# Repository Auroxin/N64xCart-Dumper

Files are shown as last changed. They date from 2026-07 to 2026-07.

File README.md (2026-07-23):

# N64xCart Dumper

N64xCart Dumper is an open hardware / firmware project for dumping Nintendo 64 cartridges as a USB mass storage device. It is based on the excellent DreamDumper64 project and the `DrmDmp64_mass` firmware, with changes for the N64xCart Dumper hardware.

## Project Status

This repository contains:

- `firmware/N64xCartDumper/` - RP2040 firmware adapted for the N64xCart Dumper board.
- `hardware/PCB/` - KiCad schematic and PCB layout.
- `hardware/production/` - production files for PCB manufacturing.
- `extras/` - extra project files, if any.

The device appears to the computer as a USB mass storage device. The virtual FAT16 disk exposes N64 cartridge data and save data files such as ROM, EEPROM, SRAM and FlashRAM where supported by the firmware.

### Known Issues – CIC Detection

The current hardware revision (v1.x) does not provide a clock signal to the CIC (Copy Integrity Check) chip inside the cartridge. Under normal operation, this clock signal is supplied by the N64 console itself. Since the clock is not connected in this hardware version, the CIC chip on the cartridge cannot function properly during operation.
Impact
Save backup functionality: ✅ NOT affected. The CIC error does not interfere with the ability to read or back up save data from the cartridge. You can safely use the backup feature.
A future hardware revision is planned to address this issue. The updated design will include the necessary clock routing to the CIC chip, allowing proper CIC detection and verification.

## Origin and Credits

This project exists because of prior open source work. Please visit and support the original authors:

- DreamDumper64 hardware project by khill25: https://github.com/khill25/Dreamdumper
- `DrmDmp64_mass` firmware by nopjne: https://github.com/nopjne/drmdmp64_mass
- TinyUSB USB stack: https://github.com/hathach/tinyusb
- Raspberry Pi Pico / RP2040 SDK ecosystem: https://github.com/raspberrypi/pico-sdk

My changes are focused on adapting the firmware and hardware layout for the N64xCart Dumper board, including the PCB layout, production files, and acrylic enclosure design.

## Hardware

The hardware in this repository was redrawn and laid out for the N64xCart Dumper form factor while following the DreamDumper64 hardware principles.

Current hardware files:

- KiCad project: `hardware/PCB/N64xCartDumper-v1.1.kicad_pro`
- Schematic: `hardware/PCB/N64xCartDumper-v1.1.kicad_sch`
- PCB layout: `hardware/PCB/N64xCartDumper-v1.1.kicad_pcb`
- Production archive: `hardware/production/N64xCart-Dumper-v1.1-20260612.zip`

## Firmware

The firmware is based on `DrmDmp64_mass`, a mass storage device firmware for DreamDumper64. It has been modified for the N64xCart Dumper hardware.

Important local changes include:

- USB product strings changed to `N64xCart Dumper`.
- Hardware pin and LED configuration adapted for this board.
- Virtual disk label/product information updated for N64xCart Dumper.
- Project files arranged under `firmware/N64xCartDumper/`.

## Building Firmware

The active firmware build entry is the CMake project in `firmware/N64xCartDumper/`.

Typical build flow:

```sh
cd firmware/N64xCartDumper
mkdir build
cd build
cmake ..
cmake --build .
(optional) put pico in bootloader mode and copy the N64xCartDumper.uf2 to the attached drive.
```

You will need a working Raspberry Pi Pico / RP2040 build environment, including the Pico SDK, CMake, a supported ARM GCC toolchain, and the TinyUSB dependencies used by this project.

Note: the included `Makefile` appears to be inherited from an earlier TinyUSB example layout and may not match the current source file names. Prefer the CMake build unless you intentionally update the Makefile.

## Buying a Finished Unit

I also sell assembled N64xCart Dumper units on AliExpress. Buying one helps support the time spent on PCB layout, testing, assembly, enclosure design, and continued open source maintenance.

- Support Us: [Product Link](https://www.aliexpress.com/item/1005012654363194.html)

Thank you for supporting this project. If you build your own, improve the design, or find a bug, contributions and feedback are welcome.

## License Notes

This repository contains code and design work derived from other open source projects. Please check the original projects and bundled third-party files for their license terms:

- `DrmDmp64_mass`: https://github.com/nopjne/drmdmp64_mass
- DreamDumper64: https://github.com/khill25/Dreamdumper
- TinyUSB license file included at `firmware/N64xCartDumper/external/tinyusb/LICENSE`

Source files inherited from `DrmDmp64_mass` include their original copyright and license headers. New N64xCart Dumper hardware files and modifications should be used with respect for the upstream projects and their licenses.

## Disclaimer

This is an independent hobbyist/open hardware project. It is not affiliated with or endorsed by Nintendo. Use it only with cartridges and data you legally own and are allowed to back up under your local laws.

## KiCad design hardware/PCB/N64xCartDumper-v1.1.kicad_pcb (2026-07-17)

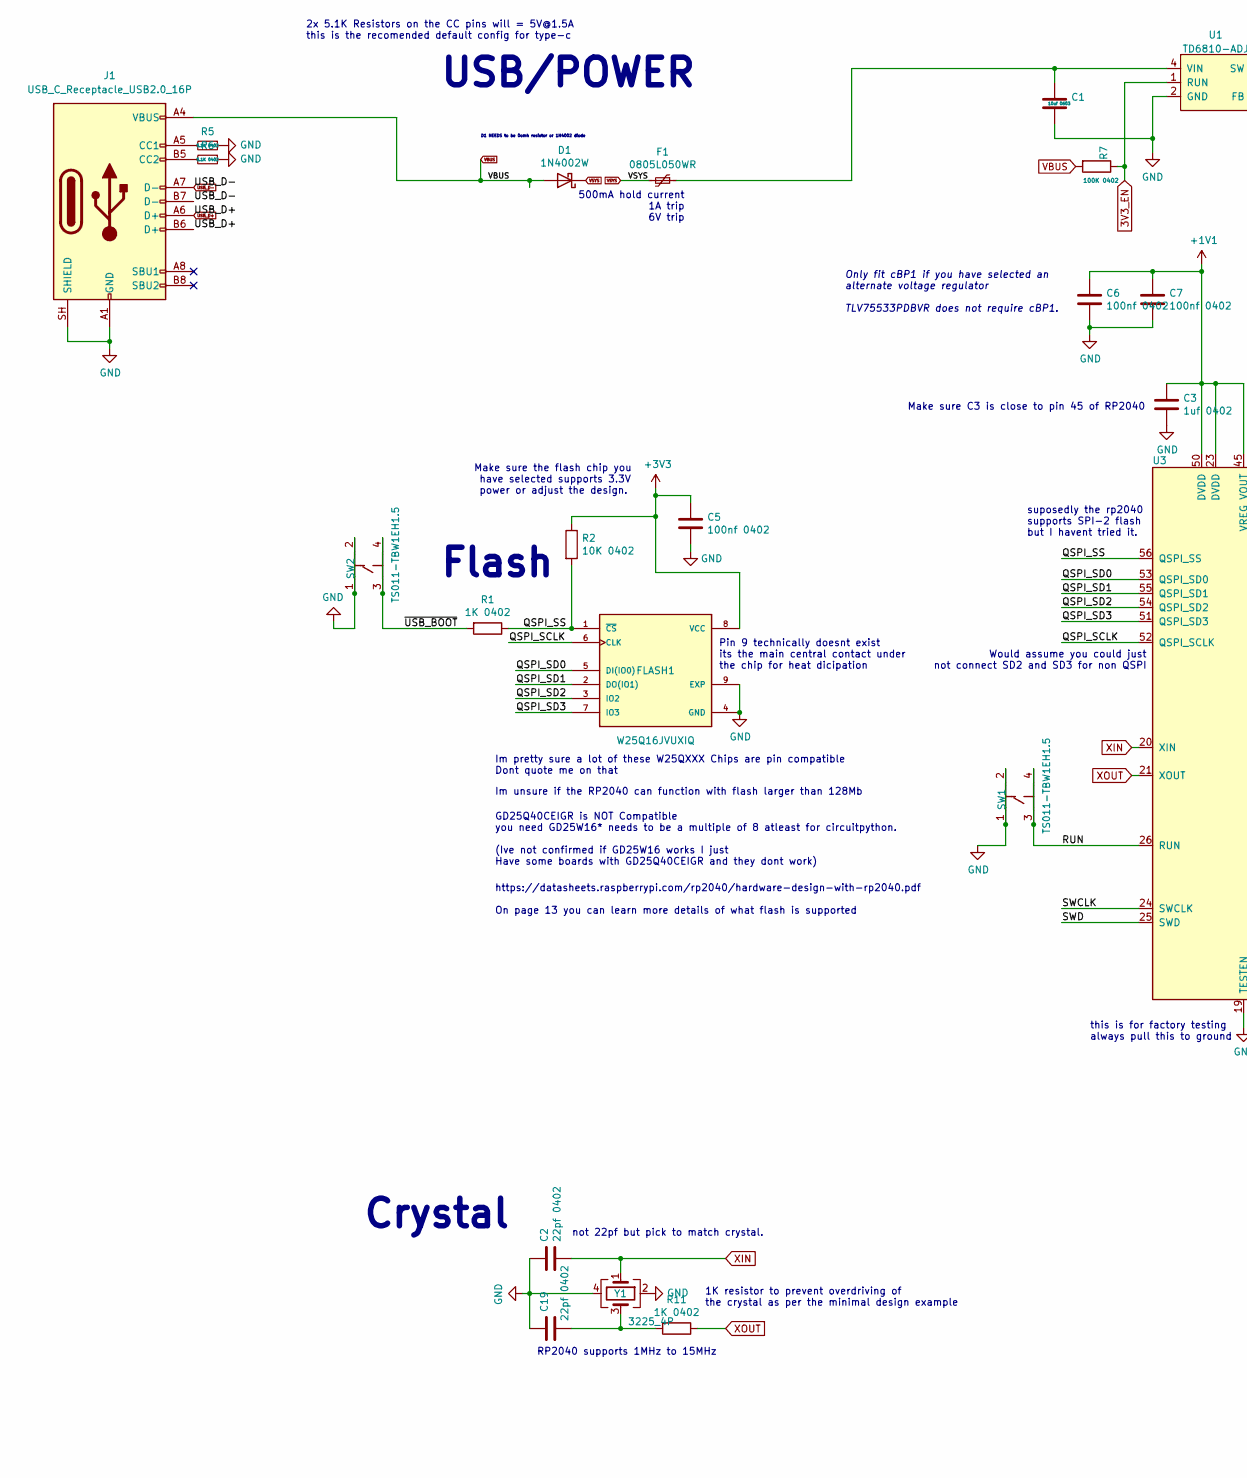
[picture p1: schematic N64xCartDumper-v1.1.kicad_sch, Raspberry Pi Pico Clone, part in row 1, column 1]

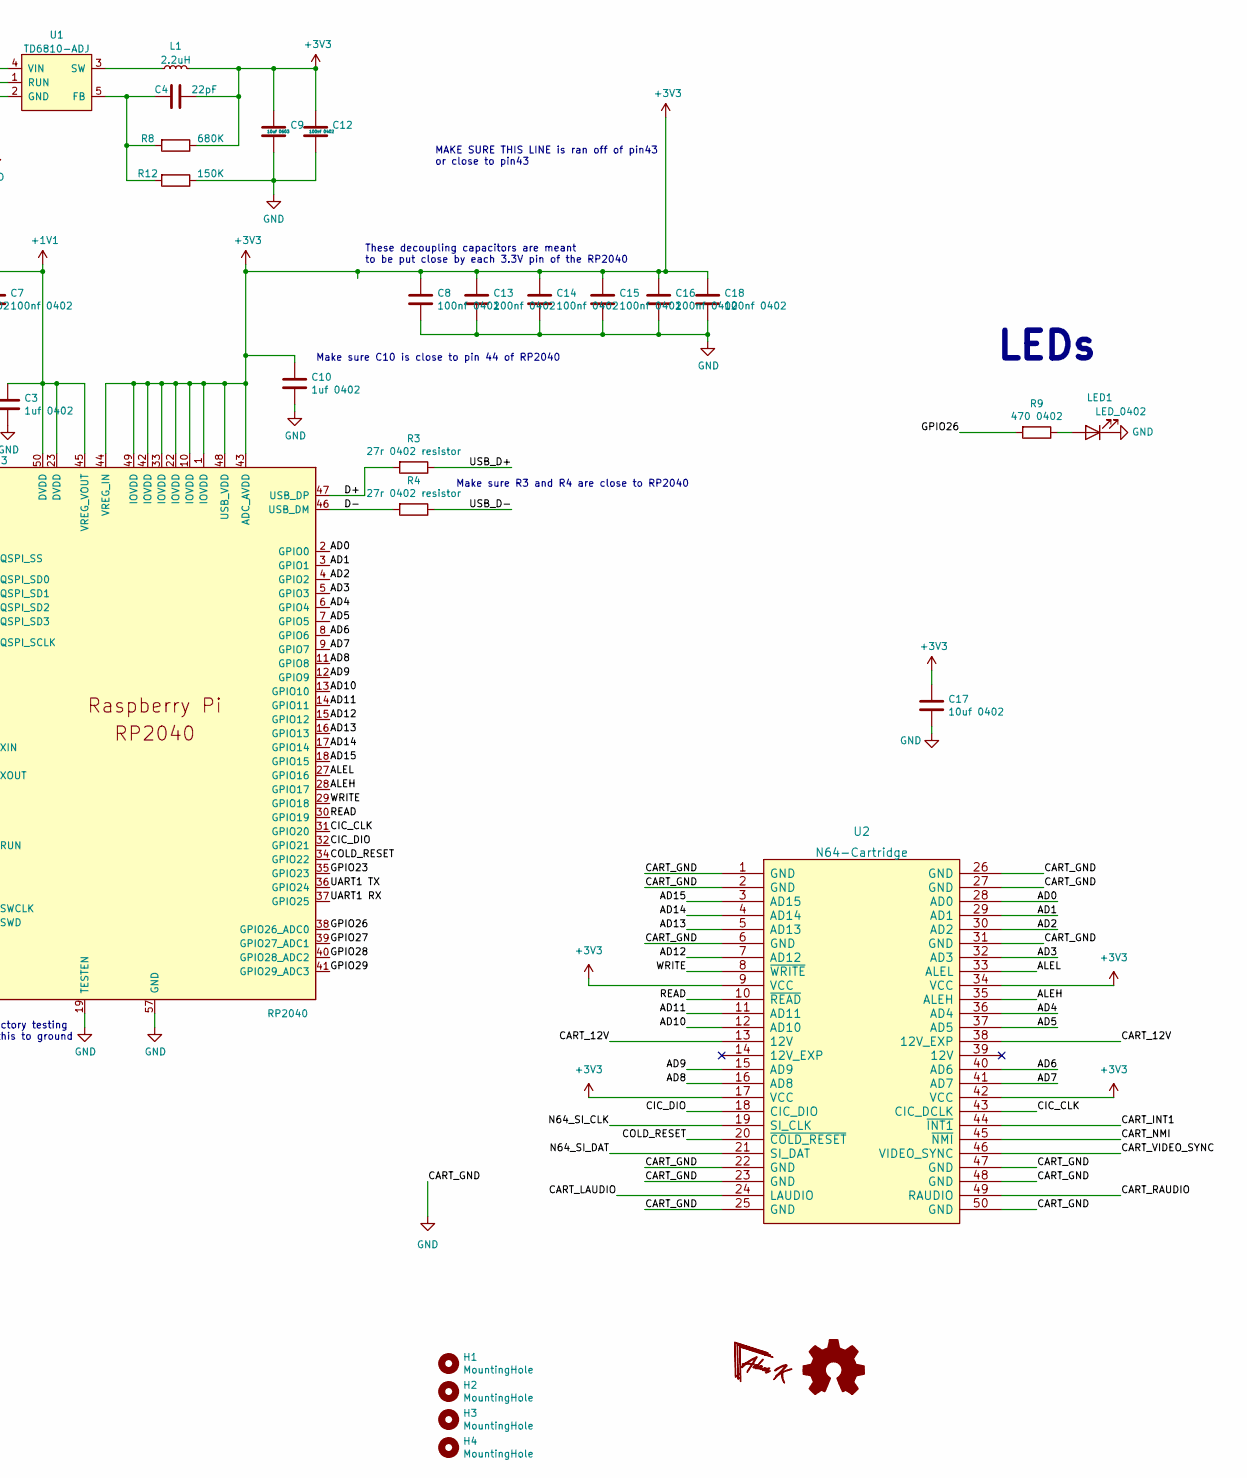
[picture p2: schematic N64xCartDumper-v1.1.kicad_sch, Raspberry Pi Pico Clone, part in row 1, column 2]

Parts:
C1, C9: 10uf 0603; C_0603_1608Metric
C2, C19: 22pf 0402; C_0402_1005Metric
C3, C10: 1uf 0402; C_0402_1005Metric
C4: 22pF; C_0402_1005Metric
C5, C6, C7, C8, C12, C13, C14, C15, C16, C18: 100nf 0402; C_0402_1005Metric
C17: 10uf 0402; C_0603_1608Metric
D1: 1N4002W; D_SOD-123
F1: 0805L050WR; Fuse_0805_2012Metric
FLASH1: W25Q16JVUXIQ; Winbond_USON-8-1EP_3x2mm_P0.5mm_EP0.2x1.6mm
H1, H2, H3, H4: MountingHole; MountingHole_2.1mm
J1: USB_C_Receptacle_USB2.0_16P; USB-C-SMD_SHOU_TYPE-C-16P-CB1.6
L1: 2.2uH; WPN252010UF2R2MT
LED1: LED_0402; LED_0603_1608Metric
R1, R11: 1K 0402; R_0402_1005Metric
R2: 10K 0402; R_0402_1005Metric
R3, R4: 27r 0402 resistor; R_0402_1005Metric
R5, R6: 5.1K 0402; R_0402_1005Metric
R7: 100K 0402; R_0402_1005Metric
R8: 680K; R_0402_1005Metric
R9: 470 0402; R_0402_1005Metric
R12: 150K; R_0402_1005Metric
SW1, SW2: TS011-TBW1EH1.5; SW-SMD_4P-L5.2-W5.2-1; Manufacturer Part TS011-TBW1EH1.5; LCSC Part Name 4*4*1.5mm 立贴 180GF 铜头轻触开关
U1: TD6810-ADJ; SOT-23-5
U2: N64-Cartridge; N64-CONN
U3: RP2040; RP2040-QFN-56; LCSC C2040
Y1: 3225_4P; Crystal_SMD_3225-4Pin_3.2x2.5mm

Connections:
3V3_EN: R7.1, U1.1 (RUN)
+1V1: C3.1, C6.1, C7.1, U3.23 (DVDD), U3.45 (VREG_VOUT), U3.50 (DVDD)
+3V3: C4.2, C5.1, C8.1, C9.1, C10.1, C12.1, C13.1, C14.1, C15.1, C16.1, C17.1, C18.1, FLASH1.8 (VCC), L1.2, R2.1, R8.1, U2.9 (VCC), U2.17 (VCC), U2.34 (VCC), U2.42 (VCC), U3.1 (IOVDD), U3.10 (IOVDD), U3.22 (IOVDD), U3.33 (IOVDD), U3.42 (IOVDD), U3.43 (ADC_AVDD), U3.44 (VREG_IN), U3.48 (USB_VDD), U3.49 (IOVDD)
/AD0: U2.28 (AD0), U3.2 (GPIO0)
/AD1: U2.29 (AD1), U3.3 (GPIO1)
/AD2: U2.30 (AD2), U3.4 (GPIO2)
/AD3: U2.32 (AD3), U3.5 (GPIO3)
/AD4: U2.36 (AD4), U3.6 (GPIO4)
/AD5: U2.37 (AD5), U3.7 (GPIO5)
/AD6: U2.40 (AD6), U3.8 (GPIO6)
/AD7: U2.41 (AD7), U3.9 (GPIO7)
/AD8: U2.16 (AD8), U3.11 (GPIO8)
/AD9: U2.15 (AD9), U3.12 (GPIO9)
/AD10: U2.12 (AD10), U3.13 (GPIO10)
/AD11: U2.11 (AD11), U3.14 (GPIO11)
/AD12: U2.7 (AD12), U3.15 (GPIO12)
/AD13: U2.5 (AD13), U3.16 (GPIO13)
/AD14: U2.4 (AD14), U3.17 (GPIO14)
/AD15: U2.3 (AD15), U3.18 (GPIO15)
/ALEH: U2.35 (ALEH), U3.28 (GPIO17)
/ALEL: U2.33 (ALEL), U3.27 (GPIO16)
/CART_12V: U2.13 (12V), U2.38 (12V_EXP)
/CART_INT1: U2.44 (~INT1)
/CART_LAUDIO: U2.24 (LAUDIO)
/CART_NMI: U2.45 (~NMI)
/CART_RAUDIO: U2.49 (RAUDIO)
/CART_VIDEO_SYNC: U2.46 (VIDEO_SYNC)
/CIC_CLK: U2.43 (CIC_DCLK), U3.31 (GPIO20)
/CIC_DIO: U2.18 (CIC_DIO), U3.32 (GPIO21)
/COLD_RESET: U2.20 (~COLD_RESET), U3.34 (GPIO22)
/D+: R3.2, U3.47 (USB_DP)
/D-: R4.2, U3.46 (USB_DM)
/GPIO23: U3.35 (GPIO23)
/GPIO26: R9.2, U3.38 (GPIO26_ADC0)
/GPIO27: U3.39 (GPIO27_ADC1)
/GPIO28: U3.40 (GPIO28_ADC2)
/GPIO29: U3.41 (GPIO29_ADC3)
/N64_SI_CLK: U2.19 (SI_CLK)
/N64_SI_DAT: U2.21 (SI_DAT)
/QSPI_SCLK: FLASH1.6 (CLK), U3.52 (QSPI_SCLK)
/QSPI_SD0: FLASH1.5 (DI(IO0)), U3.53 (QSPI_SD0)
/QSPI_SD1: FLASH1.2 (DO(IO1)), U3.55 (QSPI_SD1)
/QSPI_SD2: FLASH1.3 (IO2), U3.54 (QSPI_SD2)
/QSPI_SD3: FLASH1.7 (IO3), U3.51 (QSPI_SD3)
/QSPI_SS: FLASH1.1 (~CS), R1.1, R2.2, U3.56 (QSPI_SS)
/READ: U2.10 (~READ), U3.30 (GPIO19)
/RUN: SW1.3, SW1.4, U3.26 (RUN)
/SWCLK: U3.24 (SWCLK)
/SWD: U3.25 (SWD)
/UART1 RX: U3.37 (GPIO25)
/UART1 TX: U3.36 (GPIO24)
/WRITE: U2.8 (~WRITE), U3.29 (GPIO18)
/~USB_BOOT: R1.2, SW2.3, SW2.4
GND: C1.2, C2.1, C3.2, C5.2, C6.2, C7.2, C8.2, C9.2, C10.2, C12.2, C13.2, C14.2, C15.2, C16.2, C17.2, C18.2, C19.1, FLASH1.4 (GND), FLASH1.9 (EXP), J1.25 (SHIELD_SH), J1.26 (SHIELD_SH), J1.27 (SHIELD_SH), J1.28 (SHIELD_SH), J1.A1 (GND_A1), J1.A12 (GND_A12), J1.B1 (GND_B1), J1.B12 (GND_B12), J1.SH (SHIELD), LED1.1 (K), R5.1, R6.1, R12.1, SW1.1, SW1.2, SW2.1, SW2.2, U1.2 (GND), U2.1 (GND), U2.2 (GND), U2.6 (GND), U2.22 (GND), U2.23 (GND), U2.25 (GND), U2.26 (GND), U2.27 (GND), U2.31 (GND), U2.47 (GND), U2.48 (GND), U2.50 (GND), U3.19 (TESTEN), U3.57 (GND), Y1.2, Y1.4
unnamed: C19.2, R11.2, Y1.3
unnamed: J1.A5 (CC1_A5), R5.2
unnamed: J1.B5 (CC2_B5), R6.2
unnamed: LED1.2 (A), R9.1
unnamed: C4.1, R8.2, R12.2, U1.5 (FB)
unnamed: L1.1, U1.3 (SW)
unnamed: C1.1, F1.1, U1.4 (VIN)
USB_D+: J1.A6 (D+_A6), J1.B6 (D+_B6), R3.1
USB_D-: J1.A7 (D-_A7), J1.B7 (D-_B7), R4.1
VBUS: D1.2 (A), J1.A4 (VBUS_A4), J1.A9 (VBUS_A9), J1.B4 (VBUS_B4), J1.B9 (VBUS_B9), R7.2
VSYS: D1.1 (K), F1.2
XIN: C2.2, U3.20 (XIN), Y1.1
XOUT: R11.1, U3.21 (XOUT)

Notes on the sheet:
USB/POWER
GD25Q40CEIGR is NOT Compatible you need GD25W16* needs to be a multiple of 8 atleast for circuitpython. (Ive not confirmed if GD25W16 works I just Have some boards with GD25Q40CEIGR and they dont work)
D1 NEEDS to be 0omh resistor or 1N4002 diode
https://datasheets.raspberrypi.com/rp2040/hardware-design-with-rp2040.pdf On page 13 you can learn more details of what flash is supported
Only fit cBP1 if you have selected an alternate voltage regulator TLV75533PDBVR does not require cBP1.
Pin 9 technically doesnt exist its the main central contact under the chip for heat dicipation
Make sure R3 and R4 are close to RP2040
this is for factory testing always pull this to ground
Im unsure if the RP2040 can function with flash larger than 128Mb
Would assume you could just not connect SD2 and SD3 for non QSPI
These decoupling capacitors are meant to be put close by each 3.3V pin of the RP2040
Flash
Im pretty sure a lot of these W25QXXX Chips are pin compatible Dont quote me on that
not 22pf but pick to match crystal.
2x 5.1K Resistors on the CC pins will = 5V@1.5A this is the recomended default config for type-c
suposedly the rp2040 supports SPI-2 flash but I havent tried it.
1K resistor to prevent overdriving of the crystal as per the minimal design example
LEDs
RP2040 supports 1MHz to 15MHz
Make sure the flash chip you have selected supports 3.3V power or adjust the design.
MAKE SURE THIS LINE is ran off of pin43 or close to pin43
Crystal
500mA hold current 1A trip 6V trip
Make sure C3 is close to pin 45 of RP2040
Make sure C10 is close to pin 44 of RP2040

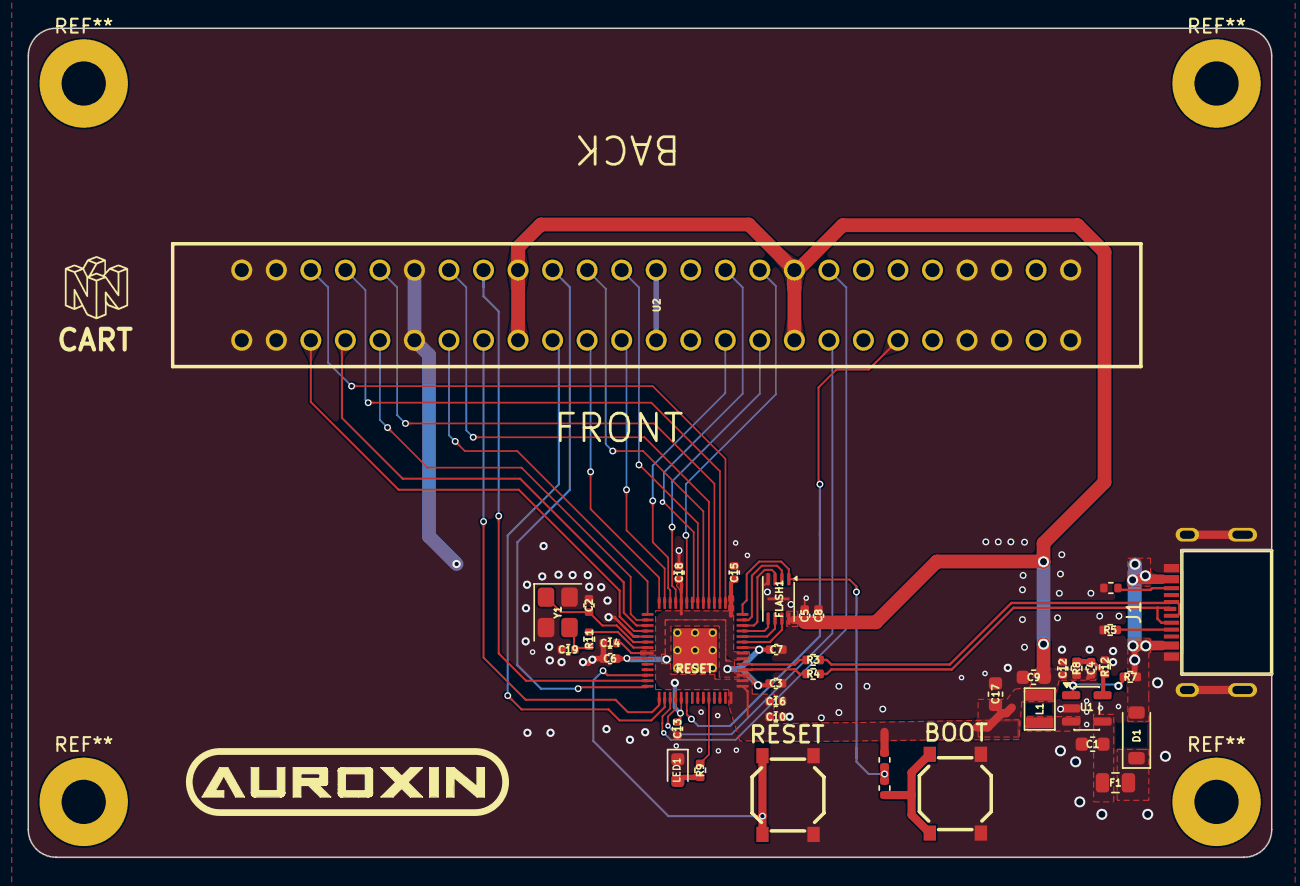
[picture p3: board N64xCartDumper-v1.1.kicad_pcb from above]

Board: 2 copper layers, 90.0 x 60.0 mm, 42 parts (1 on the bottom side), 52 nets.

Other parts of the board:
kibuzzard-6A2BC31C: G***; kibuzzard-6A2BC31C

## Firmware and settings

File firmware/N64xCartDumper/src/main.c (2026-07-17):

/**
 * SPX-License-Identifier: BSD-2-Clause 
 * Copyright (c) 2023 - NopJne
 */


#include <stdlib.h>
#include <stdio.h>
#include <string.h>



#include "bsp/board.h"
#include "tusb.h"
#include "n64cartinterface.h"

//--------------------------------------------------------------------+
// MACRO CONSTANT TYPEDEF PROTYPES
//--------------------------------------------------------------------+

/* Blink pattern
 * - 250 ms  : device not mounted
 * - 1000 ms : device mounted
 * - 2500 ms : device is suspended
 */
enum  {
  BLINK_NOT_MOUNTED = 250,
  BLINK_MOUNTED = 1000,
  BLINK_SUSPENDED = 2500,
};

static uint32_t blink_interval_ms = BLINK_NOT_MOUNTED;

void led_blinking_task(void);
void cdc_task(void);

/*------------- MAIN -------------*/
int main(void)
{
  board_init();
  cartio_init();
  // init device stack on configured roothub port
  tud_init(BOARD_TUD_RHPORT);

  while (1)
  {
    tud_task(); // tinyusb device task
    led_blinking_task();

    cdc_task();
  }
}

//--------------------------------------------------------------------+
// Device callbacks
//--------------------------------------------------------------------+

// Invoked when device is mounted
void tud_mount_cb(void)
{
  blink_interval_ms = BLINK_MOUNTED;
}

// Invoked when device is unmounted
void tud_umount_cb(void)
{
  blink_interval_ms = BLINK_NOT_MOUNTED;
}

// Invoked when usb bus is suspended
// remote_wakeup_en : if host allow us  to perform remote wakeup
// Within 7ms, device must draw an average of current less than 2.5 mA from bus
void tud_suspend_cb(bool remote_wakeup_en)
{
  (void) remote_wakeup_en;
  blink_interval_ms = BLINK_SUSPENDED;
}

// Invoked when usb bus is resumed
void tud_resume_cb(void)
{
  blink_interval_ms = BLINK_MOUNTED;
}


//--------------------------------------------------------------------+
// USB CDC
//--------------------------------------------------------------------+
void cdc_task(void)
{
  // connected() check for DTR bit
  // Most but not all terminal client set this when making connection
  // if ( tud_cdc_connected() )
  {
    // connected and there are data available
    if ( tud_cdc_available() )
    {
      // read data
      char buf[64];
      uint32_t count = tud_cdc_read(buf, sizeof(buf));
      (void) count;

      // Echo back
      // Note: Skip echo by commenting out write() and write_flush()
      // for throughput test e.g
      //    $ dd if=/dev/zero of=/dev/ttyACM0 count=10000
      tud_cdc_write(buf, count);
      tud_cdc_write_flush();
    }
  }
}

// Invoked when cdc when line state changed e.g connected/disconnected
void tud_cdc_line_state_cb(uint8_t itf, bool dtr, bool rts)
{
  (void) itf;
  (void) rts;

  // TODO set some indicator
  if ( dtr )
  {
    // Terminal connected
  }else
  {
    // Terminal disconnected
  }
}

// Invoked when CDC interface received data from host
void tud_cdc_rx_cb(uint8_t itf)
{
  (void) itf;
}

//--------------------------------------------------------------------+
// BLINKING TASK
//--------------------------------------------------------------------+
void led_blinking_task(void)
{
  static uint32_t start_ms = 0;
  static bool led_state = false;

  // Blink every interval ms
  if ( board_millis() - start_ms < blink_interval_ms) return; // not enough time
  start_ms += blink_interval_ms;

  board_led_write(led_state);
  led_state = 1 - led_state; // toggle
}
